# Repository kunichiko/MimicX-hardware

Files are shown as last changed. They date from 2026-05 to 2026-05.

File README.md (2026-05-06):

# MimicX-hardware

**製品名: Mimic X**

「Mimic X」プロジェクトのマイコン基板設計データ（KiCad）。

各バリエーションごとにサブフォルダに KiCad プロジェクトと設計仕様 (README) を
置く。共通 MCU は **WCH CH32X035G8U6** (QFN-28)、USB は Type-C で
スマートフォンと接続する。

## 基板バリエーション

- [`atari-joystick/`](atari-joystick/) — ATARI 仕様ジョイスティックアダプタ
  (D-SUB 9pin。X68000 / メガドライブ 6 ボタン互換)
- [`x68000-keyboard/`](x68000-keyboard/) — X68000 キーボードアダプタ
  (ミニ DIN 7pin。キーボード + マウス相乗り)
- （今後追加予定）

## 共通設計事項

- **MCU**: CH32X035F8U6 (TSSOP-20、48MHz、USB Full-Speed、5V トレラント)
- **USB**: Type-C Receptacle、CC1/CC2 にそれぞれ 5.1kΩ プルダウン
- **電源**: USB バスパワー (5V) を基本とし、ターゲット機からの電源供給は
  逆流防止 / 切替可能にする
- **デバッグ**: PB3 / PB4 にチップ LED ×2 (基板実装時のみ)
- **デカップリング**: VDD ピンに 4.7µF + 0.1µF を近接配置

## 関連リポジトリ

- [MimicX-app](https://github.com/kunichiko/MimicX-app) - Flutterアプリ
- [MimicX-firmware](https://github.com/kunichiko/MimicX-firmware) - マイコンファームウェア
- [MimicX-protocol](https://github.com/kunichiko/MimicX-protocol) - MIDI通信プロトコルライブラリ

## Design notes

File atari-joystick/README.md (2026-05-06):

# atari-joystick

Mimic X — ATARI 仕様ジョイスティックアダプタ基板

## 用途

スマートフォン (USB-MIDI ホスト) から CH32X035 経由で、ATARI / メガドライブ 6
ボタンファイティングパッド互換のジョイスティック信号を出力する。X68000 等の
9pin D-SUB ジョイスティックポートに接続して使用する。

## 主要部品

| 部品 | 型番 / 仕様 | 備考 |
|---|---|---|
| MCU | WCH CH32X035G8U6 | QFN28 (4×4 mm)、48MHz、5V トレラント、USB Full-Speed 内蔵 |
| USB コネクタ | USB Type-C (Receptacle, 16pin, TYPE-C-31-M-12) | スマートフォンと接続 |
| 出力コネクタ | D-SUB 9pin **メス** (CONNFLY DS1037-09FNAKT74-0CC) | ATARI/X68000 ジョイスティックポート (ホスト側オスに直挿し) |
| LED | チップ LED (0603) ×2 | デバッグ用 (PB3, PB4) |
| その他 | ESD 保護 (USB), デカップリング 0.1µF / 4.7µF, USB Type-C CC 抵抗 5.1kΩ ×2 |

## ピン割当 (CH32X035 → コネクタ)

ファームウェア `MimicX-firmware/src/functions/joystick/joystick.c` 参照。

| MCU ピン | 信号 | D-SUB 9pin | 機能 |
|---|---|---|---|
| PA0 | COMMON / TH (TIM2_CH1) | Pin 8 | MD 6B 切替検出 (input capture + DMA) |
| PA1 | Up | Pin 1 | アクティブ Low (open-drain 推奨) |
| PA2 | Down | Pin 2 | 同上 |
| PA3 | Left | Pin 3 | 同上 |
| PA4 | Right | Pin 4 | 同上 |
| PA6 | TRIG-A | Pin 6 | 同上 |
| PA7 | TRIG-B | Pin 7 | 同上 |
| PB3 | Debug LED 0 | — | (基板上、緑/赤) |
| PB4 | Debug LED 1 | — | (基板上、緑/赤) |
| — | GND  | Pin 9 | ホスト側と共通 |
| — | +5V  | Pin 5 | ホスト→当基板給電 (任意、または USB 給電のみ) |

## D-SUB 9pin (ホスト側 = オス、当基板側 = メス) ピンアサイン

X68000 等のホスト機側 D-SUB 9pin ジョイスティックポートは **オス**。本基板は
そこに直挿しできるよう **メス** を実装する。

```
   5 4 3 2 1     (D-SUB 9pin Female, looking at the mating face)
    9 8 7 6
```

| Pin | 信号 (ATARI / X68000 標準) |
|-----|---|
| 1 | Up |
| 2 | Down |
| 3 | Left |
| 4 | Right |
| 5 | +5V (host-supplied; 通常 NC) |
| 6 | TRIG-A |
| 7 | TRIG-B |
| 8 | COMMON (TH) |
| 9 | GND |

## 出力段の検討事項

- ATARI 規格では各信号線は本来 open-collector / open-drain。**5V トレラント**
  であっても CH32X035 の GPIO は出力 push-pull がデフォルトなので、ピンに
  直結するとホスト側 (X68000) のプルアップに対して干渉する可能性がある。
  - 案 A: **GPIO 出力モードを open-drain に設定** (ファーム側で `GPIO_CNF_OUT_OD`)
    かつ外付けプルアップなしで、ホスト側プルアップを利用
  - 案 B: 各信号にバスバッファ (74HC125 等) を入れる
  - 案 C: 個別 N-MOSFET (BSS138 など) で擬似 open-drain
- TH (PA0) は **入力**。MD 6 ボタンモードで本体からの信号変化を input capture
  で検出するため、ESD/サージ保護 (TVS ダイオード) の挿入を推奨

## 電源

- 通常はスマホからの USB バスパワー (5V) で動作
- D-SUB Pin 5 は接続/未接続を検討 (オプションで JP / 0Ω ジャンパ)

## レイアウトのヒント

- USB Type-C コネクタは基板端に配置
- D-SUB 9pin は反対側または隣接エッジに配置
- QFN28 (4×4 mm) 周りはデカップリング (4.7µF + 0.1µF) を近接配置 (VDD ピン直近)
- USB 信号 (DP/DM) は 90Ω 差動でルーティング (短ければそこまでシビアではない)

## 参考

- USB Type-C CC 1/2 ピンには 5.1kΩ プルダウンを VBUS と Source 認識のため必須
- 本基板は Sink (Device 側) のため、CC2 抵抗だけでも動作する場合があるが両方
  実装が無難

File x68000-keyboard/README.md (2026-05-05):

# x68000-keyboard

Mimic X — X68000 キーボードアダプタ基板 (キーボード + マウス相乗り対応)

## 用途

スマートフォン (USB-MIDI ホスト) から CH32X035 経由で、X68000 のキーボード
信号 (KEY TxD/RxD) およびマウス信号 (MSDATA) を生成し、X68000 本体の
ミニ DIN 7pin ポートに接続して使用する。

X68000 のキーボードコネクタは **マウス端子を兼用** しており、本基板も
1 つのコネクタで両方をエミュレートする (ファーム `BOARD_X68K_FULL`)。

## 主要部品

| 部品 | 型番 / 仕様 | 備考 |
|---|---|---|
| MCU | WCH CH32X035F8U6 | TSSOP-20、48MHz、5V トレラント、USB Full-Speed 内蔵 |
| USB コネクタ | USB Type-C (Receptacle, 16pin) | スマートフォンと接続 |
| 出力コネクタ | ミニ DIN 7pin オス | X68000 キーボード端子 |
| LED | チップ LED (0603) ×2 | デバッグ用 (PB3, PB4) |
| その他 | ESD 保護 (USB), デカップリング 0.1µF / 4.7µF, USB Type-C CC 抵抗 5.1kΩ ×2 |

## ピン割当 (CH32X035 → コネクタ)

ファームウェア `MimicX-firmware/src/functions/x68k_keyboard/` および
`x68k_mouse/` 参照。

| MCU ピン | 信号 | DIN 7pin | 方向 (MCU 視点) | 用途 |
|---|---|---|---|---|
| PA15 | USART2_TX (KEY TxD) | Pin 4 | OUT | キーコード送信 (2400/8N1) |
| PA16 | USART2_RX (KEY RxD) | Pin 3 | IN  | LED / リピート / MSCTRL コマンド受信 |
| PA17 | READY | Pin 5 | IN  | 1=ホスト準備完了、Low 時送信抑止 |
| PA18 | USART3_TX (MSDATA)  | Pin 2 | OUT | マウスデータ送信 (4800/8N2) |
| PA19 | (デバッグ: MSCTRL モニタ) | — | OUT | 開発時のみ。リリース基板では未使用ピンに割当て可 |
| PB3  | Debug LED 0 | — | OUT | 基板上 LED |
| PB4  | Debug LED 1 | — | OUT | 基板上 LED |
| — | +5V  | Pin 1 | — | ホスト→当基板給電 (Vcc2) |
| — | GND  | Pin 7 | — | 共通 GND |

未使用ピン (Pin 6 = REMOTE) は基板上で未接続。

## ミニ DIN 7pin (本体側 = メス、当基板側 = オス)

```
       _______
      /  4 3  \         (DIN 7pin Male, looking at the plug from outside)
     | 7  6  5 |
      \_2 1__/
```

実際の番号配置はコネクタの規格 (例: Hirose HMD-7P 系) と本体側のピンアサイン
を必ずデータシートで突き合わせること。X68000 サービスマニュアル準拠:

| Pin | 信号 |
|-----|---|
| 1 | Vcc2 (+5V) |
| 2 | MSDATA (マウスデータ、本体方向) |
| 3 | KEY RxD (本体→キーボード) |
| 4 | KEY TxD (キーボード→本体) |
| 5 | READY (本体→キーボード) |
| 6 | REMOTE (TV リモコン用、未使用) |
| 7 | GND |

## 信号レベルとバッファ

- すべて **5V TTL**
- CH32X035 は 5V トレラント入力 / 出力は 3.3V (push-pull)
  - 受信側 (PA16/PA17): 5V → 3.3V 入力可能
  - 送信側 (PA15/PA18): 3.3V 出力で X68000 (TTL) に届くか要検証
    - もし不足するなら 74LVC125 などのレベルシフタ / バッファを挿入
    - または HCT 系 (74HCT125: VIH=2.0V) を 5V 駆動でレベルシフタとして使用

## 電源

- 案 A: USB Type-C (スマホ) からのバスパワー 5V を MCU に供給。
  X68000 本体側 Vcc2 (+5V) は接続しない (ダイオード分離)
- 案 B: X68000 本体の Vcc2 を電源として使い、USB は信号のみ。
  ただしスマホが USB から Mimic X に給電できないと困るので **案 A 推奨**

VBUS と Vcc2 を **同時に通電させない** ことが重要。逆流防止ダイオード or
ジャンパ JP を入れて切替可能にする。

## レイアウトのヒント

- USB Type-C コネクタは基板の一辺に
- ミニ DIN 7pin は反対側エッジ。X68000 本体への取り回しを想定して
  ケーブル方向を考える
- TSSOP-20 周りはデカップリング (4.7µF + 0.1µF) を近接配置
- USB 信号 (DP/DM) は 90Ω 差動でルーティング
- KEY TxD / MSDATA は 1 つの DIN コネクタに集約、ESD 保護 (TVS) を入れる

## 参考

- USB Type-C CC 1/2 ピンには 5.1kΩ プルダウン (VBUS / Source 認識のため必須)
- READY は X68000 起動時にしばらく Low のままなので、送信キューを内部に持つ
  実装を前提 (FW 側で対応済み)
- マウス機能を別基板に分けたい場合は、`functions/x68k_mouse/` を外して
  USART3 関連回路を不実装にし、コネクタも MSDATA を未配線にできる

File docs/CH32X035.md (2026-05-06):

# CH32X035 ピン情報・電気的仕様 (MimicX 用ノート)

WCH CH32X035 データシート V1.7 (`CH32X035.pdf`) からの抜粋。
MimicX シリーズの全基板で共通 MCU として使用するため、各バリエーションの
回路設計時にこのファイルを参照する。

PDF 出典:
- `CH32X035.pdf` (データシート V1.7、本文 42 頁)
- `CH32X035RM.PDF` (リファレンスマニュアル — 周辺機能レジスタ詳細)

## 1. 製品ファミリ早見表

| 型番 | パッケージ | サイズ | ピッチ | GPIO 数 | ADC | OPA | CMP | USB Host | USB-C/PD |
|---|---|---|---|---|---|---|---|---|---|
| CH32X035R8T6 | LQFP64M | 10×10 mm | 0.5 mm | 60 | 14+1 | 2 | 3 | ✓ | ✓ |
| CH32X035C8T6 | LQFP48 | 7×7 mm | 0.5 mm | 46 | 10+1 | 2 | 3 | ✓ | ✓ |
| **CH32X035G8U6** | **QFN28** | **4×4 mm** | **0.4 mm** | **27** | **10+1** | **2** | **1** | **✓** | **✓** |
| CH32X035G8R6 | QSOP28 | 3.9×9.9 mm | 0.635 mm | 26 | 11+1 | 2 | 3 | ✓ | ✓ |
| CH32X035F8U6 | QFN20 | 3×3 mm | 0.4 mm | 19 | 10+1 | 2 | – | – | ✓ |
| CH32X035F7P6 | TSSOP20 | 4.4×6.5 mm | 0.65 mm | 18 | 11+1 | 1 | 1 | – | ✓ |

共通仕様: Flash 62 KB / SRAM 20 KB、TIM 高度2 + 汎用1、USART ×4、I2C、SPI、
USB 2.0 FS PHY 内蔵、PIOC、Watchdog ×2。

> ⚠️ MimicX-hardware の README には旧版で「F8U6 = TSSOP-20」と書かれて
> いるが、データシート上 **F8U6 は QFN20** (3×3 mm) が正。20 ピン TSSOP は
> F7P6 で型番が異なる。

## 2. 型番の読み方 (Series Product Naming Rules)

```
CH32  X  03  5  G   8   U   6
↑     ↑  ↑   ↑ ↑   ↑   ↑   ↑
|     |  |   | |   |   |   └ 温度範囲 (6: -40〜85℃)
|     |  |   | |   |   └─── パッケージ (T:LQFP / U:QFN / R:QSOP / P:TSSOP / M:SOP)
|     |  |   | |   └─────── Flash サイズ (8 = 64KB)
|     |  |   | └─────────── ピン数 (J:8 / A:16 / F:20 / G:28 / K:32 / T:36 / C:48 / R:64 / W:68 / V:100 / Z:144)
|     |  |   └───────────── サブファミリ (35: USB + USB PD/Type-C 接続性)
|     |  └───────────────── 製品タイプ (0 = QingKe V2/V4、≤48MHz)
|     └──────────────────── デバイスファミリ (X = RISC-V 専用 IO)
└────────────────────────── ベース (CH32 = WCH 32-bit MCU)
```

## 3. CH32X035G8U6 (QFN28) ピン配置

データシート Table 2-1 から QFN28 列を抽出。**MimicX で実際に使うピンを
太字** で示す。

| Pin | 信号名 | Type | デフォルト機能 | 主なリマップ機能 |
|---:|---|---|---|---|
| 0 (center pad) | **GND** | P | GND (露出パッド) | — |
| 1 | PC15 | I/O/A | **CC2** | T2C3_6 / T1ET_4 |
| 2 | **VDD** | P | VDD | — |
| 3 | PC0 | I/O/A | A10 | TX2_3 / T2C4_5 / T2C4_6 / T1C1_3 / T2BK_4 |
| 4 | PC3 | I/O/A | RST / C1N0 / C2N1 / C3N1 / A13 | RTS2_3 / T1C4_3 / T2C3N_4 / T2C1N_2 / RTS2_4 |
| 5 | **PA0** | I/O/A | **T2C1** / CTS2 / C1P1 / **A0** | T2C1_2 |
| 6 | **PA1** | I/O/A | RTS2 / T2C2 / C1O / O1N2 / O2N2 / A1 | CTS2_1 / T2C2_2 |
| 7 | **PA2** | I/O/A | TX2 / T2C3 / O2O1 / C3N0 / A2 | RTS2_1 / T2ET_5 / T2C3_1 / T2ET_6 |
| 8 | **PA3** | I/O/A | RX2 / T2C4 / O1O0 / A3 | T3C1_3 / T2C4_1 / CTS3_2 |
| 9 | **PA4** | I/O/A | CS / CK2 / O2O0 / A4 | RTS3_2 / T3C2_3 |
| 10 | PA5 | I/O/A | SCK / O2N0 / A5 | TX4_1 / CTS4_4 |
| 11 | **PA6** | I/O/A | MISO / T3C1 / O1N0 / A6 | CK4_1 / RTS4_4 / T1BK_1 |
| 12 | **PA7** | I/O/A | MOSI / T3C2 / O2P0 / A7 | T1C1N_1 / TX1_3 / CTS4_1 |
| 13 | PB0 | I/O/A | TX4 / O1P0 / A8 | T1C2N_1 |
| 14 | **PB3** | I/O/A | TX3 / C3O / O2P1 | T2C3_2 / T2C3N_5 / T2C3_3 / T2C3N_6 |
| 15 | **PB4** | I/O/A | RX3 / O1P2 | T2C4_2 / T3C1_1 / T2BK_5 / T2C4_3 / T2BK_6 |
| 16 | **PB1 / PB5** | I/O/A | RX4 / O2N1 / A9 / CK3 / O1O1 / T1BK | T1C3N_1 / CK1_2 / T3C2_1 / CK3_1 / T1BK_2 |
| 17 | PB6 | I/O/A | T1C1N / CTS3 / O1N1 | T1C1N_2 / CTS3_1 |
| 18 | PB7 | I/O/A | T1C2N / O2P2 / RTS3 | RTS3_1 / T1C2N_2 |
| 19 | PB8 | I/O/A | T1C3N / O1P1 | CK3_2 / CK4_3 / T1C3N_2 |
| 20 | PB9 | I/O | CK1 / T1C1 / MCO | TX4_3 / CK1_1 / T1C1_1 / T1C1_2 |
| 21 | PB10 | I/O | TX1 / T1C2 | T1C2_1 / T1C2_2 / TX1_2 |
| 22 | PB11 | I/O | T1C3 / RX1 | T1C3_1 / T1C3_2 / RX1_2 / T2C1N_6 |
| 23 | PB12 | I/O | — | CK1_3 / T1C4_2 / T2C2N_5 / T2C2N_6 |
| 24 | PC19 | I/O/A | **DCK** / PIOC_IO1 / C1P0 | T2C1_5 / T3C1_2 / SCL_3 / SDA_5 / RX3_1 / RX4_4 / T2C1_6 |
| 25 | PC18 | I/O | **DIO** / PIOC_IO0 | TX3_1 / T2C1N_5 / SDA_3 / SCL_5 / T1ET_2 / T1ET_3 / T3C2_2 |
| 26 | PC16 (内部 PC11 と短絡) | I/O/A | **UDM** / T1C4 / CTS1 | TX4_2 / SCL_2 / SDA_4 / RX4_5 / CTS1_1 / T1C4_1 |
| 27 | PC17 (内部 PC10 と短絡) | I/O/A | **UDP** / RTS1 / T1ET | TX4_5 / SDA_2 / SCL_4 / RX4_2 / RTS1_1 / T1ET_1 |
| 28 | PC14 | I/O/A | **CC1** | T1C3_4 / T2C2_6 |

> Type 略号: I = TTL/CMOS シュミット入力、O = 三状態出力、A = アナログ入出力、P = 電源

### 内部短絡されているピン (重要)

データシート Note 4 / Note 5:

- **Pin 16: PB1 と PB5 が内部で短絡 & 封止** (G8U6 / G8R6 共通)。両方を
  出力モードに設定することは禁止。
- **Pin 26: PC16 と PC11 が内部短絡**。Pin 27: **PC17 と PC10 が内部短絡**。
  両方を出力モードに設定することは禁止。USB アプリケーションでは PC10 /
  PC11 をフローティング入力 (リセット直後の既定値) に維持すること。
- **Pin 4 (PC3) は QSOP28 / TSSOP20 でのみ RST 機能あり**。QFN28 (G8U6)
  では RST 不可、通常 GPIO として扱う。

## 4. MimicX 系での標準ピン割当案

| 用途 | QFN28 Pin | 信号 | 主機能 |
|---|---:|---|---|
| GND (露出パッド) | 0 | GND | 必ず広い面パッドにベタ落とす |
| VDD | 2 | VDD | 4.7 µF + 0.1 µF 近接配置 |
| USB D− | 26 | PC16/UDM | USB-C D− |
| USB D+ | 27 | PC17/UDP | USB-C D+ |
| Type-C CC1 | 28 | PC14/CC1 | 5.1 kΩ プルダウン (Sink) |
| Type-C CC2 | 1 | PC15/CC2 | 5.1 kΩ プルダウン (Sink) |
| SWD DCK | 24 | PC19 | プログラム/デバッグ |
| SWD DIO | 25 | PC18 | プログラム/デバッグ |
| LED 0 | 14 | PB3 | デバッグ LED (active-low) |
| LED 1 | 15 | PB4 | デバッグ LED (active-low) |

### atari-joystick 固有割当 (ATARI / X68000 標準)

ホスト機側 D-SUB 9pin はオス、当基板側はメス (CONNFLY DS1037-09FNAKT74-0CC)。

| ATARI 信号 | D-SUB 9pin | QFN28 Pin | MCU 信号 | 備考 |
|---|---:|---:|---|---|
| Up | 1 | 6 | PA1 | open-drain (FW 設定) |
| Down | 2 | 7 | PA2 | 同上 |
| Left | 3 | 8 | PA3 | 同上 |
| Right | 4 | 9 | PA4 | 同上 |
| +5V (host) | 5 | — | — | 通常 NC |
| TRIG-A | 6 | 11 | PA6 | open-drain (FW 設定) |
| TRIG-B | 7 | 12 | PA7 | 同上 |
| COMMON / TH | 8 | 5 | PA0 | 入力 (TIM2_CH1, MD 6B 検出) |
| GND | 9 | (0) | GND | 共通 |

## 5. 電気的仕様 (抜粋)

### 絶対最大定格 (Table 3-1)

| 項目 | 最小 | 最大 | 単位 |
|---|---:|---:|---|
| 動作周囲温度 TA | -40 | 85 | ℃ |
| 保管温度 TS | -40 | 125 | ℃ |
| VDD 電圧 | -0.3 | 6.0 | V |
| 各 IO ピン VIN | -0.3 | VDD+0.3 | V |
| ESD (HBM) | — | 4 | kV |
| VDD ピン総電流 IVDD | — | 150 | mA |
| GND ピン総電流 IGND | — | 200 | mA |
| 各 IO シンク電流 | — | 40 | mA |
| 各 IO ソース電流 | — | 30 | mA |

### 推奨動作条件 (Table 3-2)

| 項目 | 条件 | 最小 | 最大 | 単位 |
|---|---|---:|---:|---|
| FSYS (内部バス周波数) | — | — | 48 | MHz |
| VDD | USB / PD 無効 | 2.0 | 5.5 | V |
| VDD | **USB / PD 有効** | **3.0** | **5.3** | **V** |
| VDD | ADC 有効 | 2.5 | 5.5 | V |

> MimicX は USB バスパワー (5V) で動作するが、**USB 通信用途では VDD = 3.3V
> に降圧する** (次節「USB 通信時の VDD 必須事項」参照)。5V トレラント GPIO の
> ため、ATARI 側ホストの 5V 信号は GPIO ピンに直結してよい。

### USB 通信時の VDD 必須事項 (重要)

データシートだけ読むと「USB / PD 有効時 VDD = 3.0〜5.3V」なので 5V バスパワー
直結でも動きそうに見えるが、**実機では Android (Pixel 等の規格準拠ホスト) で
enumerate されない** という症状が出る。原因は以下:

- CH32X035 の内蔵 USB FS トランシーバの **D+/D- 出力レベルは VDD に直結**
  している。
- Full Speed device の attach 時、内部 1.5kΩ プルアップにより D+ がアイドル
  HIGH に引き上げられるが、その電圧は **VDD と同電位** になる。
- USB 2.0 仕様では D+/D- の VOH 上限は概ね 3.6V (絶対最大定格 3.6V)。
  VDD = 5V のとき D+ アイドルが 5V となり、これを超える。
- iPhone / Mac / Windows PC は寛容で 5V でも enumeration が通ってしまうが、
  Android (特に Pixel) は仕様準拠で電気的異常として拒否し、デバイスは
  認識されない (`/dev/bus/usb/` に device entry が出ない)。

**結論**: USB を使う MimicX 系基板では VDD = 3.3V が必須。VBUS (5V) と VDD の
間に LDO (例: TI LP5907MFX-3.3, LCSC C76858) を挟むこと。

#### 切り分けの目安 (デバッグ時)

USB-MIDI デバイスが Android で `MIDIデバイスが見つからない` と出るとき:

1. `adb shell ls -la /dev/bus/usb/*/` でデバイスファイルが追加されているか
   - ホストコントローラ (e.g. `001/001`) しか無ければ enumeration 失敗
2. CC1 / CC2 にテスタを当てる (ホスト接続時)
   - 片方が ~0.4V、もう片方が 0V → CC ロール検出は OK
3. **D+ ピンを GND 基準で測定**
   - 3.3V ≒ 正常 (Full Speed attach 完了)
   - **5.0V → VDD = 5V 駆動 になっている (要 LDO 追加)**

## 6. 参照

- データシート: `CH32X035.pdf` (V1.7、章 2 = ピン定義、章 3 = 電気仕様、
  章 4 = パッケージ・型番)
- リファレンスマニュアル: `CH32X035RM.PDF`
- WCH 公式 (datasheet 配布元): https://wch-ic.com

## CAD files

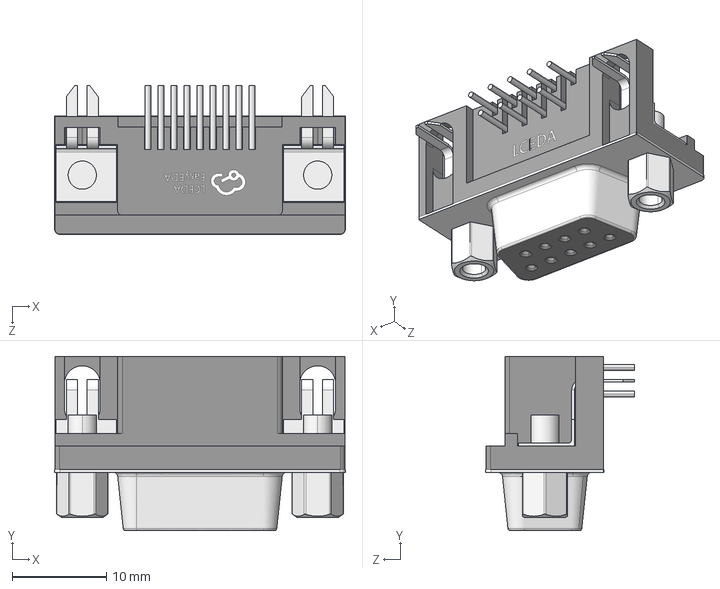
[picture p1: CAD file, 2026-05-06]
atari-joystick/parts/CONNFLY_Elec_DS1037_09FNAKT74_0CC/DSUB-TH_DMR-9S.step
30.9 x 18.5 x 15.8 mm

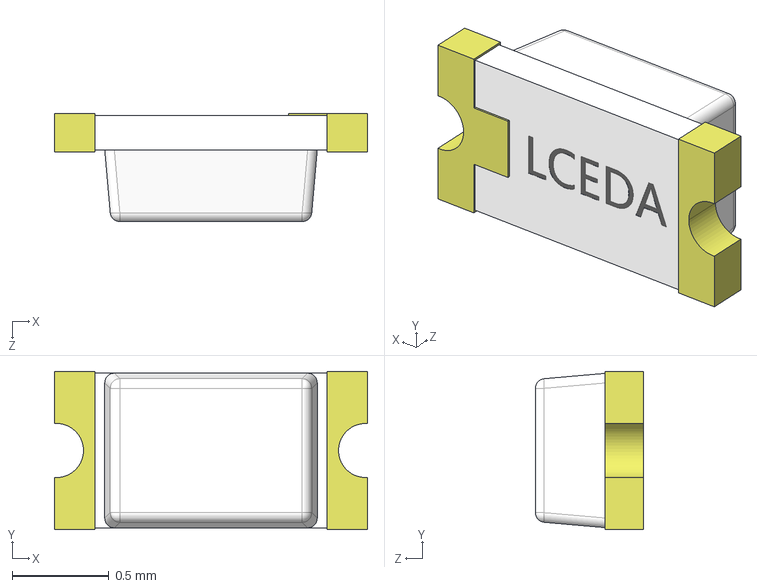
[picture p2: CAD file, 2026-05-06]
atari-joystick/parts/Everlight_Elec_19_217_GHC_YR1S2_3T/LED0603-RD-YELLOW.STEP
1.62 x 0.82 x 0.56 mm

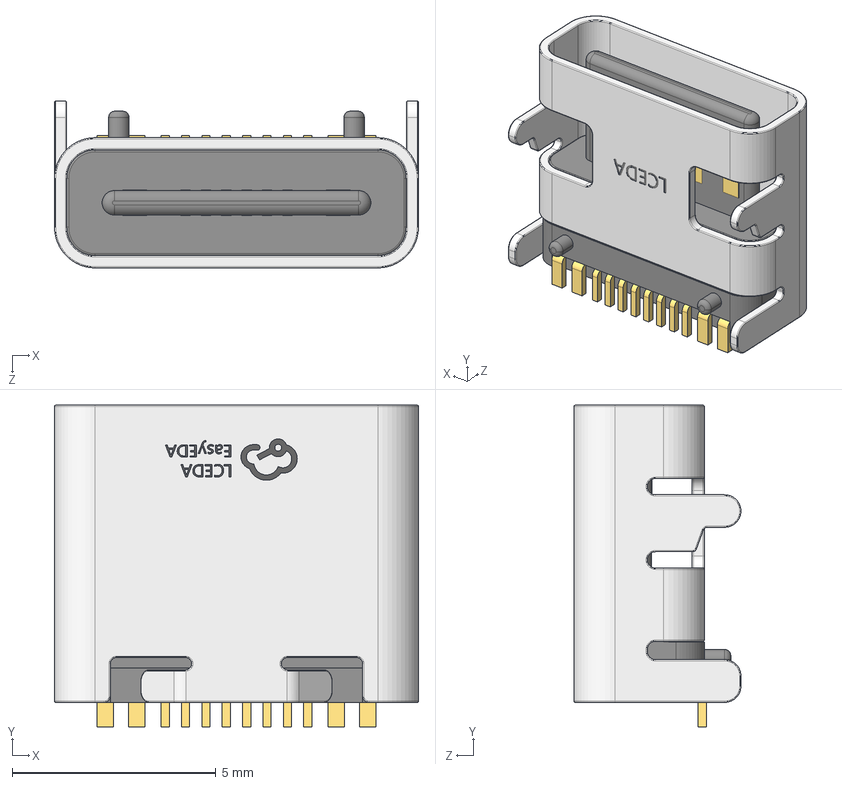
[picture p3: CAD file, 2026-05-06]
atari-joystick/parts/Korean_Hroparts_Elec_TYPE_C_31_M_12/USB-C_SMD-TYPE-C-31-M-12.step
8.94 x 7.90 x 4.10 mm

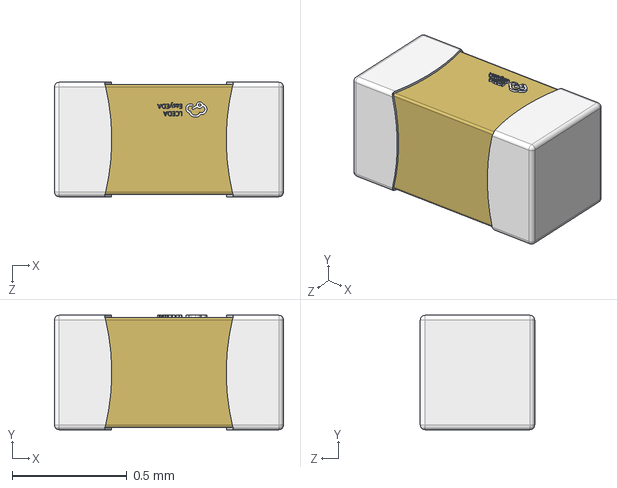
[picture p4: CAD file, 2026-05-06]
atari-joystick/parts/Samsung_Electro_Mechanics_CL05A105KA5NQNC/C0402_L1.0-W0.5-H0.5.step
1.00 x 0.5 x 0.5 mm

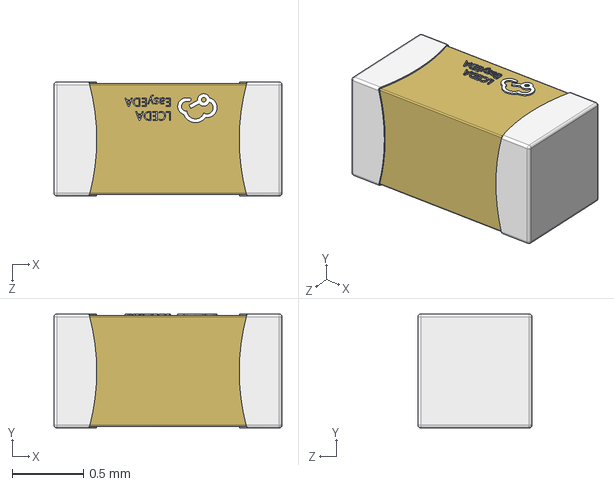
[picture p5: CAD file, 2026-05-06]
atari-joystick/parts/Samsung_Electro_Mechanics_CL10A475KO8NNNC/C0603_L1.6-W0.8-H0.8.step
1.60 x 0.8 x 0.8 mm

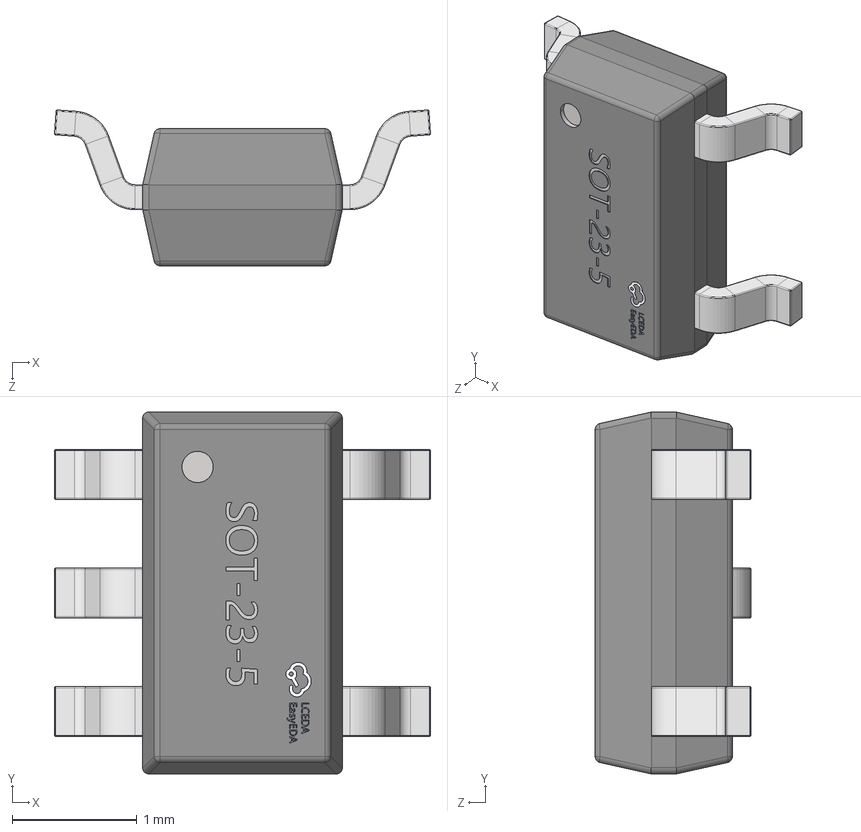
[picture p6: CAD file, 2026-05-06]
atari-joystick/parts/TECH_PUBLIC_LP5907MFX_3_3/SOT-23-5_L2.9-W1.6-H1.1-LS2.8-P0.95.step
3.01 x 2.90 x 1.25 mm

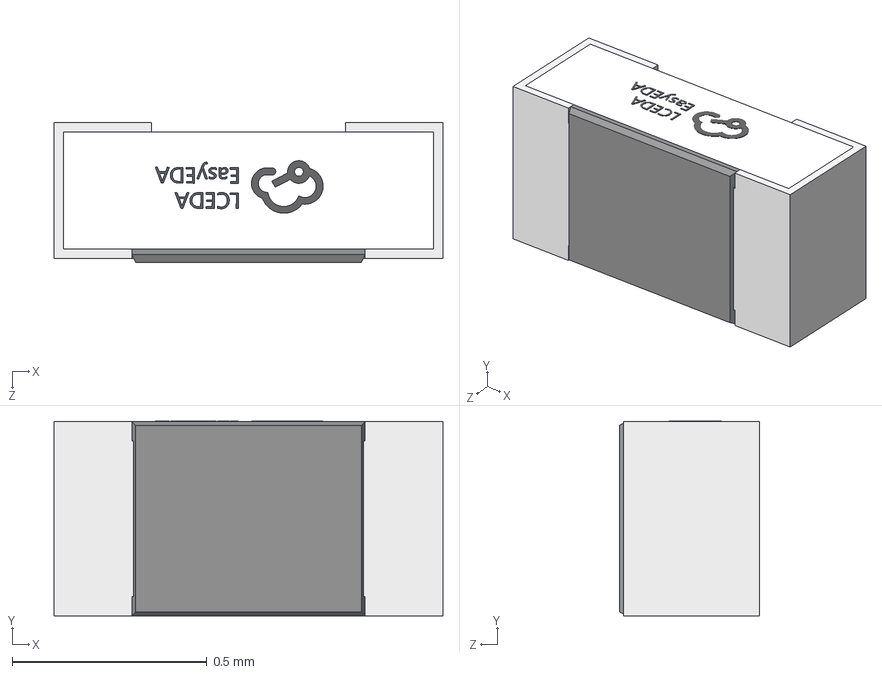
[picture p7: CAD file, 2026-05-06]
atari-joystick/parts/UNI_ROYAL_0402WGF4700TCE/R0402_L1.0-W0.5-H0.4.step
1.00 x 0.501 x 0.36 mm

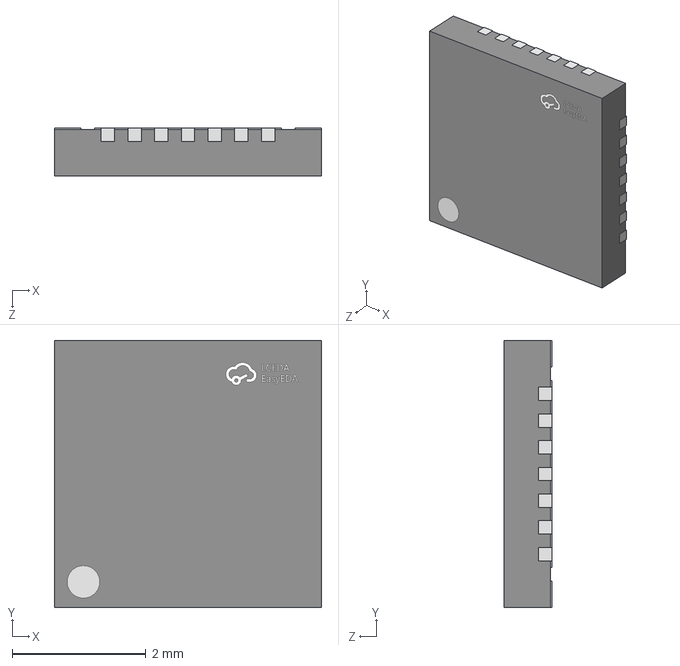
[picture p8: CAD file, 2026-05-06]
atari-joystick/parts/WCH_CH32X035G8U6/QFN-28_L4.0-W4.0-P0.40-BL-EP2.8.STEP
4.00 x 4.00 x 0.721 mm

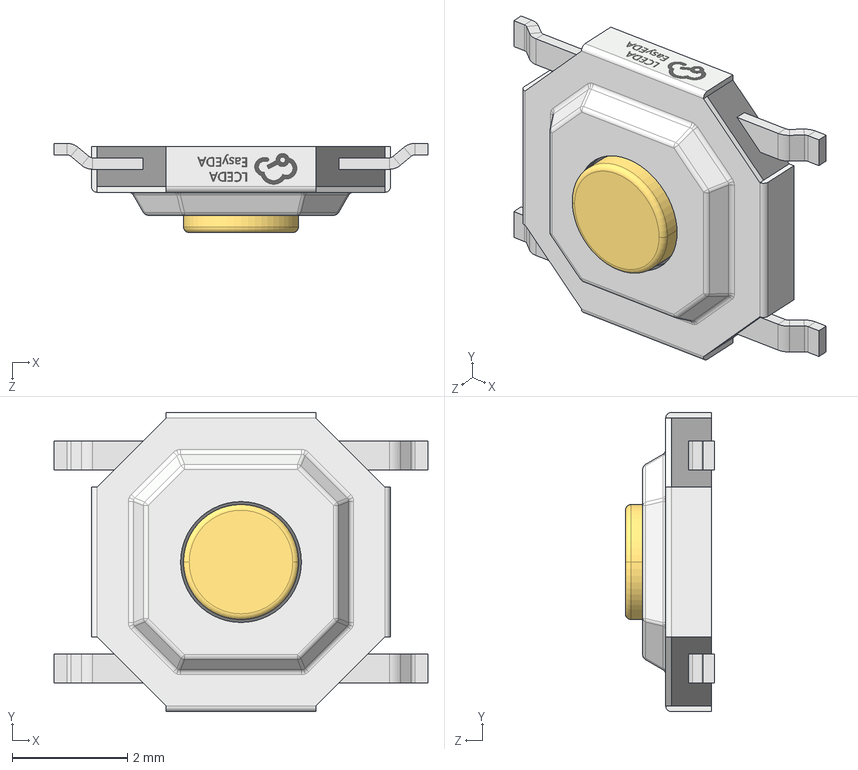
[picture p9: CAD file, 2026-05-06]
atari-joystick/parts/XKB_Connectivity_TS_1187A_B_A_B/SW-SMD_4P-L5.1-W5.1-P3.70-LS6.5-TL_H1.5.STEP
6.50 x 5.20 x 1.55 mm

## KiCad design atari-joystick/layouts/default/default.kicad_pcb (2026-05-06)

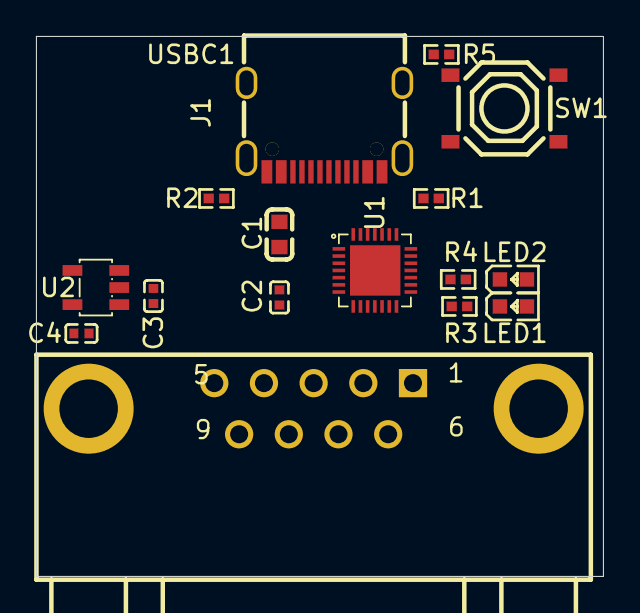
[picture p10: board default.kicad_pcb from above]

Board: 2 copper layers, 31.5 x 30.0 mm, 16 parts (0 on the bottom side), 21 nets, no tracks yet.

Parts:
C1: 4.7µF ±10%; C0603
C2: 100nF ±10%; C0402
C3, C4: 1µF ±10%; C0402
J1: DSUB-TH_DS1037-09FNAKT74-0CC
LED1, LED2: LED0603-RD
R1, R2: 5.1kΩ ±1%; R0402
R3, R4: 470Ω ±1%; R0402
R5: 4.7kΩ ±1%; R0402
SW1: SW-SMD_4P-L5.1-W5.1-P3.70-LS6.5-TL_H1.5
U1: QFN-28_L4.0-W4.0-P0.40-BL-EP2.8
U2: SOT-23-5_L3.0-W1.7-P0.95-LS2.8-BR
USBC1: USB-C_SMD-TYPE-C-31-M-12_1

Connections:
GND: C1.2, C2.2, C3.2, C4.2, J1.9, R1.2, R2.2, U1.29, U2.2, USBC1.A1B12, USBC1.B1A12
PB3: R3.2, U1.14
PB4: R4.2, U1.15
VBUS: C3.1, U2.1, U2.3, USBC1.A4B9, USBC1.B4A9
VDD33: C1.1, C2.1, C4.1, LED1.2, LED2.2, SW1.1, SW1.2, U1.2, U2.5
cathode: LED1.1, R3.1
cathode-1: LED2.1, R4.1
cc1: R1.1, USBC1.A5
cc2: R2.1, USBC1.B5
common: J1.8, U1.5
dn: U1.26, USBC1.A7, USBC1.B7
down: J1.2, U1.9
dp: R5.2, U1.27, USBC1.A6, USBC1.B6
left: J1.3, U1.7
right: J1.4, U1.6
shell: J1.10, J1.11
terminal_b: R5.1, SW1.3, SW1.4
triga: J1.6, U1.11
trigb: J1.7, U1.8
up: J1.1, U1.12
usbc-shell: USBC1.1, USBC1.2, USBC1.3, USBC1.4

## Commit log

2026-05-05 製品名「Mimic X」を README に追加
2026-05-05 リブランディング: リポジトリ名を MimicX-hardware に変更
    旧リポジトリ名 smart-retro-hid-* を MimicX-* に置換 (README)
2026-05-05 基板バリエーション用サブフォルダと設計仕様 README を追加
    - atari-joystick/ — ATARI / X68000 9pin ジョイスティック互換アダプタ
    - x68000-keyboard/ — X68000 ミニ DIN 7pin (キーボード+マウス相乗り)
    各サブ README にピン割当 (FW と整合)、コネクタアサイン、信号レベル/バッファ、
    電源・レイアウト方針、共通設計事項 (CH32X035F8U6 / USB-C 5.1kΩ / デバッグ
    LED 等) を記載。KiCad プロジェクト本体は KiCad で作成して同フォルダに置く。
2026-05-06 atari-joystick: atopile による初版回路実装と CH32X035 リファレンス追加
    - atari_joystick.ato: USB Type-C → CH32X035G8U6 → D-SUB 9pin の結線を記述
    - parts/: LCSC ID 経由で取得した部品 (KiCad symbol/footprint/STEP) を pin
    - WCH CH32X035G8U6 (C7437027, QFN28)
    - Korean Hroparts TYPE-C-31-M-12 (C165948)
    - CONNFLY DS1037-09FNAKT74-0CC (C75749, D-SUB 9pin Female 右アングル)
    - Samsung / UNI-ROYAL の 0402/0603 パッシブ
    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
    [C0402_L1.0-W0.5-H0.5.step, C0603_L1.6-W0.8-H0.8.step, DSUB-TH_DMR-9S.step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]
2026-05-06 atari-joystick: デバッグ LED 追加と 3D モデルオフセット永続化
    - parts/leds.ato: 緑/赤 0603 LED の wrapper module (LedGreen0603 /
    LedRed0603) を追加。anode/cathode の signal 名を統一。
    - parts/Everlight_..._3T (LCSC C72043, 緑) と
    parts/Hubei_KENTO_..._KT-0603R (LCSC C2286, 赤) を ato create part で取得
    - atari_joystick.ato: 抽象 LED → 上記 wrapper に差し替え。BOM/PCB から
    silent drop していた問題を解消 (LED1, LED2 が PCB に乗るように)
    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
    [LED0603-RD-YELLOW.STEP, default.kicad_pcb]
2026-05-06 atari-joystick: VBUS と MCU の間に 3.3V LDO を挿入し USB 互換性を確保
    CH32X035 の USB FS トランシーバの D+/D- 出力レベルは VDD に直結している
    ため、VDD = 5V (VBUS 直結) のままだと D+ アイドル電圧が 5V となり USB 規格
    (VOH max ≈ 3.6V) を逸脱する。iPhone / Mac は寛容で問題なく動作するが、
    Pixel 等の規格準拠ホスト (Android) では enumerate されない。
    主な変更:
    - LP5907MFX-3.3 (LCSC C23380874) ベースの Ldo3V3 モジュールを新設
    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
    [C0402_L1.0-W0.5-H0.5.step, R0402_L1.0-W0.5-H0.4.step, SOT-23-5_L2.9-W1.6-H1.1-LS2.8-P0.95.step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]
2026-05-07 デバッグLEDのピンを変更
